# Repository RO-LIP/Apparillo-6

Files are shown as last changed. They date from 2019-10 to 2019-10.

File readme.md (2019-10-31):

# Apparillo 6
Portabler Lautsprecher auf Basis der Audible 17 mit Raspberry Pi und moOde audio player.
Alternativ zur Audible 17 bieten sich auch andere Lautsprecher an.
https://moodeaudio.org/
https://www.lautsprecherbau.de/magazine/lautsprecherbau-magazin-2014/februar-2014/audible-17-einfach-besser-hoerbar_8636,de,901172,16142

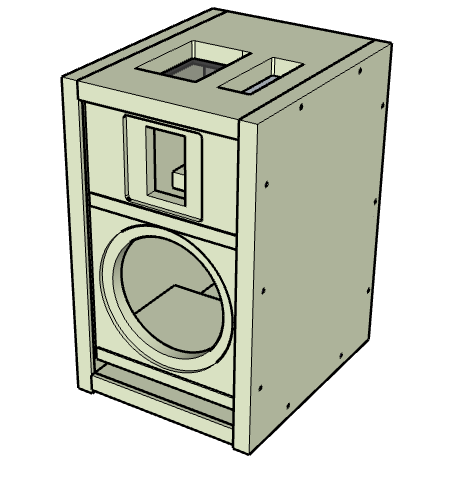
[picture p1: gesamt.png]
Gesamtansicht

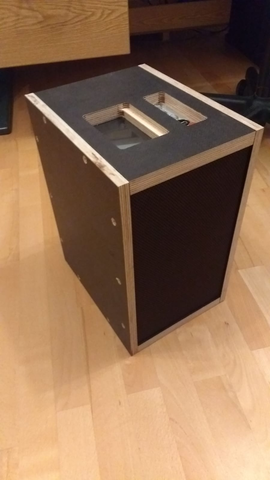
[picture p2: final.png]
Final

## Features:
- WebUi und MPD
- WiFi Access Point (AP) Mode
- Bluetooth, Airplay, Spotify, UPnP
- Touch LCD-Display mit automatischer Abschaltung
- ca. 15h Akkulaufzeit
- Nach Ausschalten werden alle Verbraucher durch Relais vom Akku getrennt

## Bauteile:
- Audible 17 (Gradient AXP 06, Gradient GAM 100)
- Raspberry Pi 3B+
- Hifiberry AMP+
- Lithium-Polymer Akku (4S 16000mAh)
- 5" LCD Touchscreen (HDMI)
- Relais
- ProtoHat
- Stacking Header
- 2 Taster, Rotary Encoder, Ladebuchse
- Schutzgitter mit Lautsprecherstoff bezogen

## Setup
1. Lautsprecher und Frequenzweiche zusammenbauen (Apparillo6-Pläne.skp). Alternativ bieten sich auch andere Bausätze von Udo Wohlgemuth an.
1. Hifiberry und Raspberry Pi zusammenbauen
1. moOde OS von https://moodeaudio.org/ installieren und einstellen
1. Bauteile auf ProtoHat löten
1. Frequenzweiche, Rotary Encoder, Buttons, HDMI anschließen (SchaltungApparillo6.fzz)
1. Spannungsversorgung des RasPi und des Displays (USB) an die Relais anschließen
1. Ladebuchse an Akku anschließen
1. config.txt auf RasPi ersetzten
1. io-apparillo6.py in home Verzeichnis kopieren
1. io-apparillo6.service als systemd Service einrichten
1. gpiozero installieren
1. Msuik auf RasPi kopieren
1. Alles fixieren und Lautpsrecher schließen
1. Alle Funktionen testen
1. Kleine Spende für stetige Weiterentwicklung und umfangreichen Support an Tim Curtis von moOde Audio schicken https://moodeaudio.org/

## ToDo
- Einfachere/Automatisierte Installation
- Messung und Darstellung des Akkuladezustands
- Stereo Variante oder modulares System
- Zusätzlicher analoger Input

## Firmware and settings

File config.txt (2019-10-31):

disable_splash=1
disable_overscan=1
hdmi_drive=2
dtparam=i2c_arm=on
dtparam=i2s=on
dtparam=audio=off
dtoverlay=justboom-dac
#dtoverlay=pi3-disable-wifi
#dtoverlay=pi3-disable-bt


#### Eigene Einstellungen #####
#dtoverlay=hifiberry-dacplus
#dtoverlay=justboom-dac

max_usb_current=1

##5Inch Touch display mit 15:9 -- 16:9 sollte am Display eingestellt werden!##
hdmi_force_hotplug=1
hdmi_group=2
hdmi_mode=87
config_hdmi_boost=7
hdmi_cvt 800 480 60 6
display_hdmi_rotate=1

##Touch eingabe wird in /etc/X11/xorg.conf.d/40-libinput.conf gedreht mit: Option "CalibrationMatrix" "0 1 0 -1 0 1 0 0 1"


##pin fuer abschaltfunktion UVLO bzw zu halten der spannungsversorgung uvlo
dtoverlay=gpio-poweroff,gpiopin=9,active_low

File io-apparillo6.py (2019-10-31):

#!/usr/bin/python3
from gpiozero import RGBLED, Button, LED, DigitalOutputDevice
from time import sleep
from subprocess import getoutput
from signal import pause
from os import system

'''
Script zum aktivieren verschiedener Ein- und Ausgabegeraete
-Rotary Encoder zur Lautstaerkeregelung
-RGB LED zur Anzeige/Visualisierung des Lautstaerkepegels
-Taster zum Pausieren der Wiedergabe und Herunterfahren des Pi
-Schalter/Taster und Relais zum abschalten des LCD
-Timer zum Abschalten des LCD
-Startup Lautstaerke
-UVLO selbsthaltung

Relays sollten über Transistor angesteuert werden:
https://www.elektronik-kompendium.de/public/schaerer/powsw3.htmhttps://www.elektronik-kompendium.de/public/schaerer/powsw3.htm
'''


'''
Einstellungen in diesem Script: 

Pins und Betriebssystem(os) muss eingestellt werden. 
Befehle werden dann automatisch angepasst.
Bei moOde muss Rotary Encoder ueber WebUI aktiviert werden (Standartpins 4,5(GPIO23,24))


Einstellungen an Pi:

Prinzipielle Einstellungen:
Service in systemd für dieses Script einrichten
Kontrollieren ob in /boot/config.txt folgende Parameter gesetzt sind:
disable_splash=1
hdmi_drive=2
dtparam=audio=off
max_usb_current=1

UVLO: 
Das Relay zum Halten der Verbindung LiPo-UVLO wird über einen Transistor (GPIO9) angesteuert. 
Die Einstellung dazu muss in /boot/config.txt hinzugefuegt werden: 
dtoverlay=gpio-poweroff,gpiopin=9,active_low

LCD:
Das Relay zum Ein-/Ausschalten des Touchscreens wird über einen Transistor (GPIO11) angesteuert.
Einstellungen fuer 5Inch 15:9 Touch Display. Am Display selbst sollte 16:9 eingestellt werden 
Der Touchscreen wird in /boot/config.txt konfiguriert:
hdmi_force_hotplug=1
hdmi_group=2
hdmi_mode=87
config_hdmi_boost=7
hdmi_cvt 800 480 60 6
display_hdmi_rotate=1
Touch eingabe wird in /etc/X11/xorg.conf.d/40-libinput.conf gedreht mit: 
Option "CalibrationMatrix" "0 1 0 -1 0 1 0 0 1"
'''


#Alle Buttons pulled up ausser rotary button

os = "moode"
#os="volumio" '''alle volumio befehle muessen noch getestet werden'''


'''
Festlegen der Pins fuer die angeschlossenen I/O
GPIO22,23,24 werden normalerweise fuer Rotary verwendet
Diese GPIOs nicht verwenden: 
GPIO0,GPIO1
GPIO0,1,26 sind nicht auf Proto HAT.
GPIO2,3,18,19,20,21 werden von I2C/JustboomAmp/HifiberryDAC/HifiberryAMP2 verwendet
GPIO2,3,18,19,20,21,4 wird von HifiberryAMP2 verwendet

'''

laser_BTN_P = 7         #Taster um LCD ein und aus zu schalten
laser_LED_P = 8
missile_BTN_P = None    #Nicht an GPIO angeschlossen. Schaltet Apparillo ein
missile_LED_P = None    #Wird evtl nicht an GPIO angeschlossen sondern an UVLO
lcd_RELAY_P = 11 #sclk  #Relay+Transistor zum einschalten des LCDs; Bildschirm ist an wenn Pin high
lcd_time = 600          #Zeit in Sekunden nach denen der LCD automatisch ausgeschaltet wird.
uvlo_relay = 9   #miso  #Relay+Transistor zum Unterbrechen der Messung des UVLO; eingestellt in /boot/config
rot_clk_P = 23          #Pins des Rotary Encoders; Mittlerer Pin auf GND
rot_data_P = 24         #Vertausche CLK und Data um Drehrichtung zu aendern
rot_BTN_P = 22          #pulled down button zum pausieren und herunterfahren des pi
rot_RGB_P_red = 14      #RGB LED zum visualisiern des Lautstaerkepegels
rot_RGB_P_green = 27
rot_RGB_P_blue = 17     #Die blaue Led wird noch nicht bzw. fuer nix wichtiges verwendet
vol_red = 80            #Lautstaerke ab der die LED rot leuchtet
vol_green = 40          #Lautstaerke ab der die LED rot leuchtet
holdtime = 5            #Dauer bis jeweiliger Taster als gehalten erkannt wird







def volume(arg=""): #Kann mit leer, integer oder "up <step>" "dn <step>" aufgerufen werden, dann als string (in "") damit als 1 argument erkannt wird
    arg = str(arg)
    if os == "moode":
        getoutput("/var/www/vol.sh " + arg)
        try:
            return(int(getoutput("/var/www/vol.sh")))
        except ValueError:
            return(1000)
    elif os == "volumio":
        getoutput("volumio volume " + arg)


def vol_color(): #Bestimmt die Farbe der LED passend zur Lautstaerke und stellt die LED ein
    vol = volume()
    if vol == 1000:
        newcol = rot_RGB.color
    elif vol <= vol_green:
        newcol = (0, 1, 0)
    elif vol >= vol_red:
        newcol = (1, 0, 0)
    elif vol <= vol_mid:
        r = ((vol - vol_green)/(vol_mid - vol_green))
        newcol = (r, 1, 0)
    else:
        g = ((vol - vol_mid)/(vol_red -vol_mid))
        newcol = (1, 1-g, 0)
    rot_RGB.pulse(fade_in_time=0, fade_out_time=0.1, on_color=rot_RGB.color, off_color=newcol, n=1, background=True) #Led fade von altem zu neuem wert


def toggle(): #Wechselt zwischen play und pause
    if os == "moode":
        print("ich toggle")
        getoutput("mpc toggle")
    elif os == "volumio":
        getoutput("volumio toggle")

def rotation(): #Aendert Lautstaerke bei Rotation. Nur bei Volumio noetig
    rot_data.when_pressed = upvolume
    rot_data.when_released = downvolume

def upvolume():
    rot_data.when_pressed = None
    rot_data.when_released = None
    volume("plus")

def downvolume():
    rot_data.when_pressed = None
    rot_data.when_released = None
    volume("minus")

def held(): #Wenn der BTN des Rotarys gehalten wird, wird der Raspy heruntergefahren
    #print("bitte lass nicht los damit ich nicht herunterfahre")
    rot_RGB.blink(on_time=0.5,off_time=0.5,on_color=(0,0,1),off_color=(1,0,0),n=6,background=False)
    if rot_BTN.is_held: #Wenn der BTN weiter gehalten wird, wird der vorgang abgebriochen und alles geht weiter wie vorher
        #print("danke")
        rot_RGB.blink(on_time=0.5,off_time=0.5,on_color=(0,0,1),off_color=(0,1,0),n=2,background=False)
    else:
        shutdown()

def shutdown():
    print("Ich wuerde jetzt abschalten! poweroff!")
    system("poweroff")

def toggle_lcd(): #Schaltet Relay fuer Bildschirm ein und aus
    if lcd_RELAY.value == True:
        laser_LED.off()
        lcd_RELAY.off()
    elif lcd_RELAY.value == False:
        laser_LED.blink(on_time=lcd_time,off_time=None, n=1, background=True)
        lcd_RELAY.blink(on_time=lcd_time, off_time=None, n=1, background=True)
    laser_BTN.wait_for_release(timeout=0.2)
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
